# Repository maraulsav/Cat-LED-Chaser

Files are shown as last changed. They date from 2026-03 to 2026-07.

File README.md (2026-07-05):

# Cat-LED-Chaser
Hii! This is a cat shaped LED chaser. I wanted to make it as a keychain to be gifted to someone special for me during my highschool graduation later..
This is the final form of my cat LED casher



And here's the youtube video of my journey making this cat LED casher: https://www.youtube.com/watch?v=RgV0-7eemWM
See full built documentation at JOURNAL (1).md

## 3D View
Front



Back



## Features
- NE555P (555 Timer)
- CD4017 (Integrated Circuit)
- 10 LEDs
- 2 Capacitor
- 2 Resistor
- 1 Variable Resistor
- 1 Slide witch
- 1 Battery Socket
- 1 Battery

## PCB
My PCB is made in KiCad These are the footprints I used
- Battery: Battery_Panasonic_CR2032-HFN_Horizontal_CircularHoles
- Capacitor_THT:CP_Radial D5.0mm_P2.00mm
- LED_THT:LED_D3.0mm
- Resistor_THT:R_Axial_DIN0207_L6.3mm_D2.5mm_P7.62mm_Horizontal
- Variable Resistor: Potentiometer_THT: Potentiometer_Vishay_T93YA_Vertical
- SW SPST: Button_Switch_THT_SPST:SW_Push_1P2T_Vertical_E-Switch_800UDP8P1A1M6
- TestPoint: Connector PinSocket 2.54mm:PinSocket 1x01 P2.54mm Vertical
- NE555P: Package_DIP: DIP-8_W7.62mm
- 4017: footprints: N16

Here is my schematic:



and my PCB:



## BOM
You can see the BOM in Blinky Board-bom.csv files

## Additional Thingy
Thankyou for HackClub and  KiCad for making this project possible

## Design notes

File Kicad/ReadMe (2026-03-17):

Here's all the KiCad files. 
If you want to built your own LED chaser you can use my schematic design here!

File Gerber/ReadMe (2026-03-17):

Here's the gerber files of my LED casher cat shaped. 
You can download it and compres it all into one zip files. 
Then, you can upload it in the JLCPCB, it should be automatically generate the shape

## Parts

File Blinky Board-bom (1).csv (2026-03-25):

Name | Purpose | Quantity | Total Cost (USD) | Link | Distributor
Tokopedia Delivery | To deliver the components | 1 | 2.86 | https://www.tokopedia.com/cart/checkout?t_id=1774435593040&t_st=2&t_pp=cart&t_efo=cart&t_ef=&t_sm=&t_spt=cart | Tokopedia
E-Post Delivery | Delivery for the JLCPCB | 1 | 1.50 | https://cart.jlcpcb.com/quote?spm=jlcpcb.Public.2006 | JLCPCB
PCB Printing 5x | For holding all the components together | 1 | 4.00 | https://cart.jlcpcb.com/quote?spm=jlcpcb.Public.2006 | JLCPCB
Battery CR2032 | Power supply | 2 | 0.65 | https://www.tokopedia.com/panasonic-battery-indonesia/panasonic-baterai-kancing-lithium-coin-cr2016-cr2025-cr2032-cr2032-1pc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 | Tokopedia
Battery Socket CR2032 5x | For the battery placement | 1 | 0.27 | https://www.tokopedia.com/iwantelectronics/soket-baterai-3v-tempat-holder-case-baterai-kancing-3v-cr2032-battery-socket-cr2032-socket-battery-3v-cr2032-socket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 | Tokopedia
slide switch | To make sure the battery is not overused. regulating power | 1 | 0.10 | https://www.tokopedia.com/indo-ware/3-pin-saklar-geser-mini-toggle-switch-slide-1p2t-3pin-ss12d00-g3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 | Tokopedia

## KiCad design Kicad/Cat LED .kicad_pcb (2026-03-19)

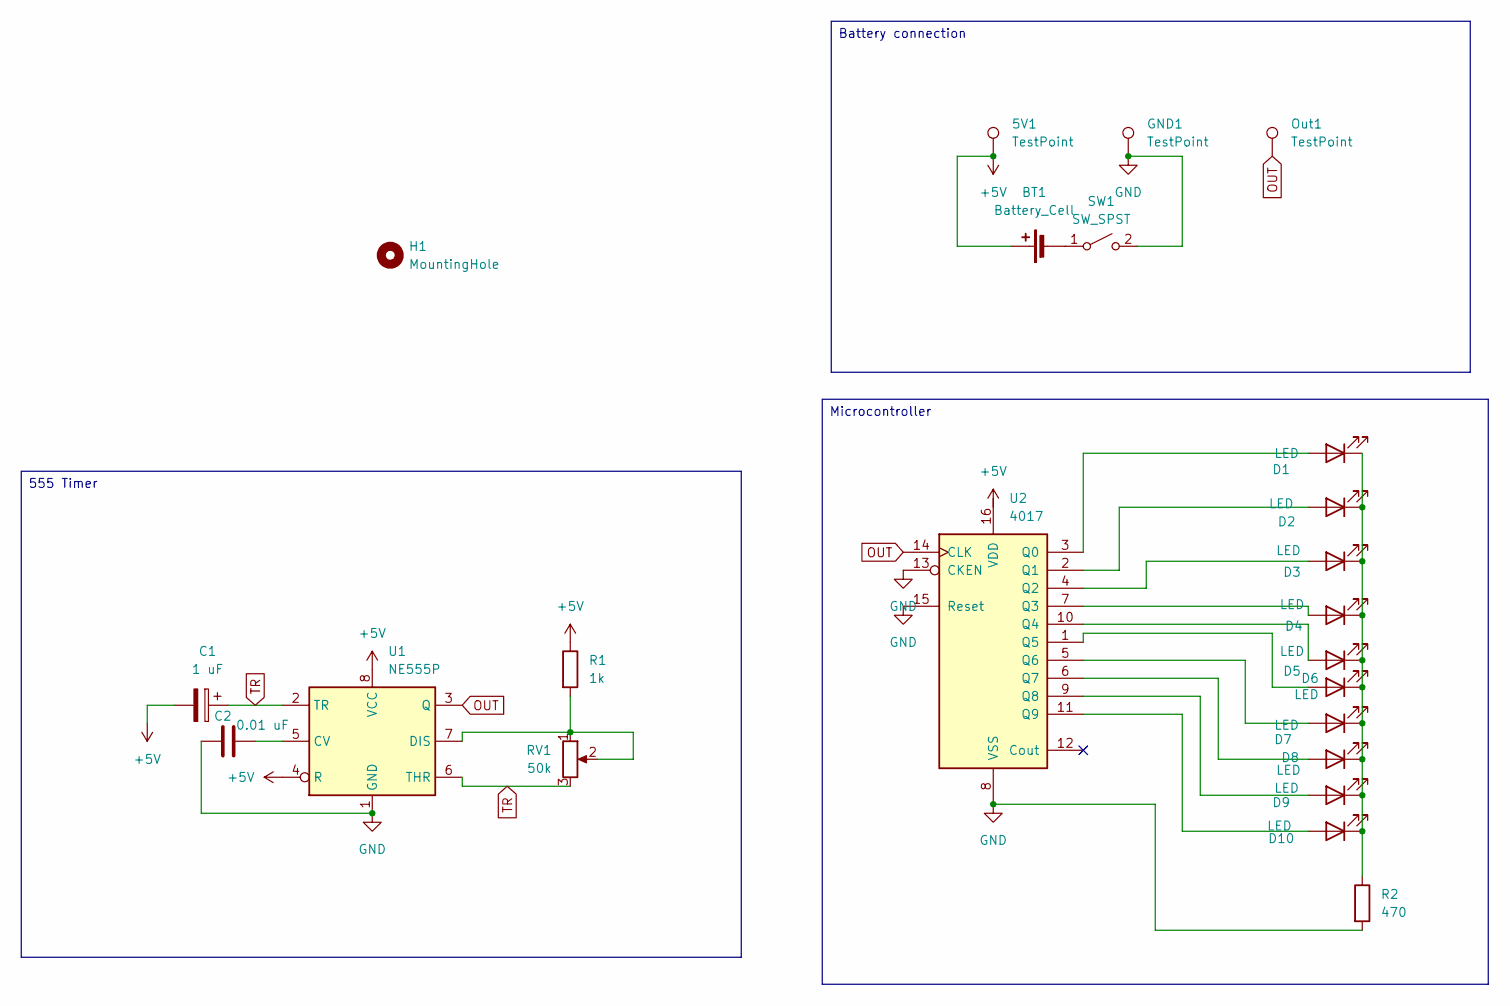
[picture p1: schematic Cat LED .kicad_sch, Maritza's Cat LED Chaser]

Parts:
5V1: TestPoint; PinSocket_1x01_P2.54mm_Vertical
BT1: Battery_Cell; Battery_Panasonic_CR2032-HFN_Horizontal_CircularHoles
C1: 1 uF; CP_Radial_D5.0mm_P2.00mm
C2: 0.01 uF; CP_Radial_D5.0mm_P2.00mm
D1, D2, D3, D4, D5, D6, D7, D8, D9, D10: LED; LED_D3.0mm
GND1: TestPoint; PinSocket_1x01_P2.54mm_Vertical
H1: MountingHole; MountingHole_4mm
Out1: TestPoint; PinSocket_1x01_P2.54mm_Vertical
R1: 1k; R_Axial_DIN0207_L6.3mm_D2.5mm_P7.62mm_Horizontal
R2: 470; R_Axial_DIN0207_L6.3mm_D2.5mm_P7.62mm_Horizontal
RV1: 50k; Potentiometer_Vishay_T93YA_Vertical
SW1: SW_SPST; SW_Push_1P2T_Vertical_E-Switch_800UDP8P1A1M6
U1: NE555P; DIP-8_W7.62mm
U2: 4017; N16

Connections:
+5V: 5V1.1, BT1.1 (+), C1.2, R1.1, U1.4 (R), U1.8 (VCC)
GND: C2.2, GND1.1, R2.2, SW1.2 (B), U1.1 (GND), U2.8 (VSS), U2.13 (CKEN), U2.15 (Reset)
unnamed: BT1.2 (-), SW1.1 (A)
unnamed: D1.2 (A), U2.3 (Q0)
unnamed: D1.1 (K), D2.1 (K), D3.1 (K), D4.1 (K), D5.1 (K), D6.1 (K), D7.1 (K), D8.1 (K), D9.1 (K), D10.1 (K), R2.1
unnamed: D2.2 (A), U2.2 (Q1)
unnamed: D3.2 (A), U2.4 (Q2)
unnamed: D4.2 (A), U2.7 (Q3)
unnamed: D5.2 (A), U2.10 (Q4)
unnamed: D6.2 (A), U2.1 (Q5)
unnamed: D7.2 (A), U2.5 (Q6)
unnamed: D8.2 (A), U2.6 (Q7)
unnamed: D9.2 (A), U2.9 (Q8)
unnamed: D10.2 (A), U2.11 (Q9)
unnamed: C2.1, U1.5 (CV)
unnamed: R1.2, RV1.1, RV1.2, U1.7 (DIS)
OUT: Out1.1, U1.3 (Q), U2.14 (CLK)
TR: C1.1, RV1.3, U1.2 (TR), U1.6 (THR)

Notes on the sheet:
Microcontroller
Battery connection
555 Timer

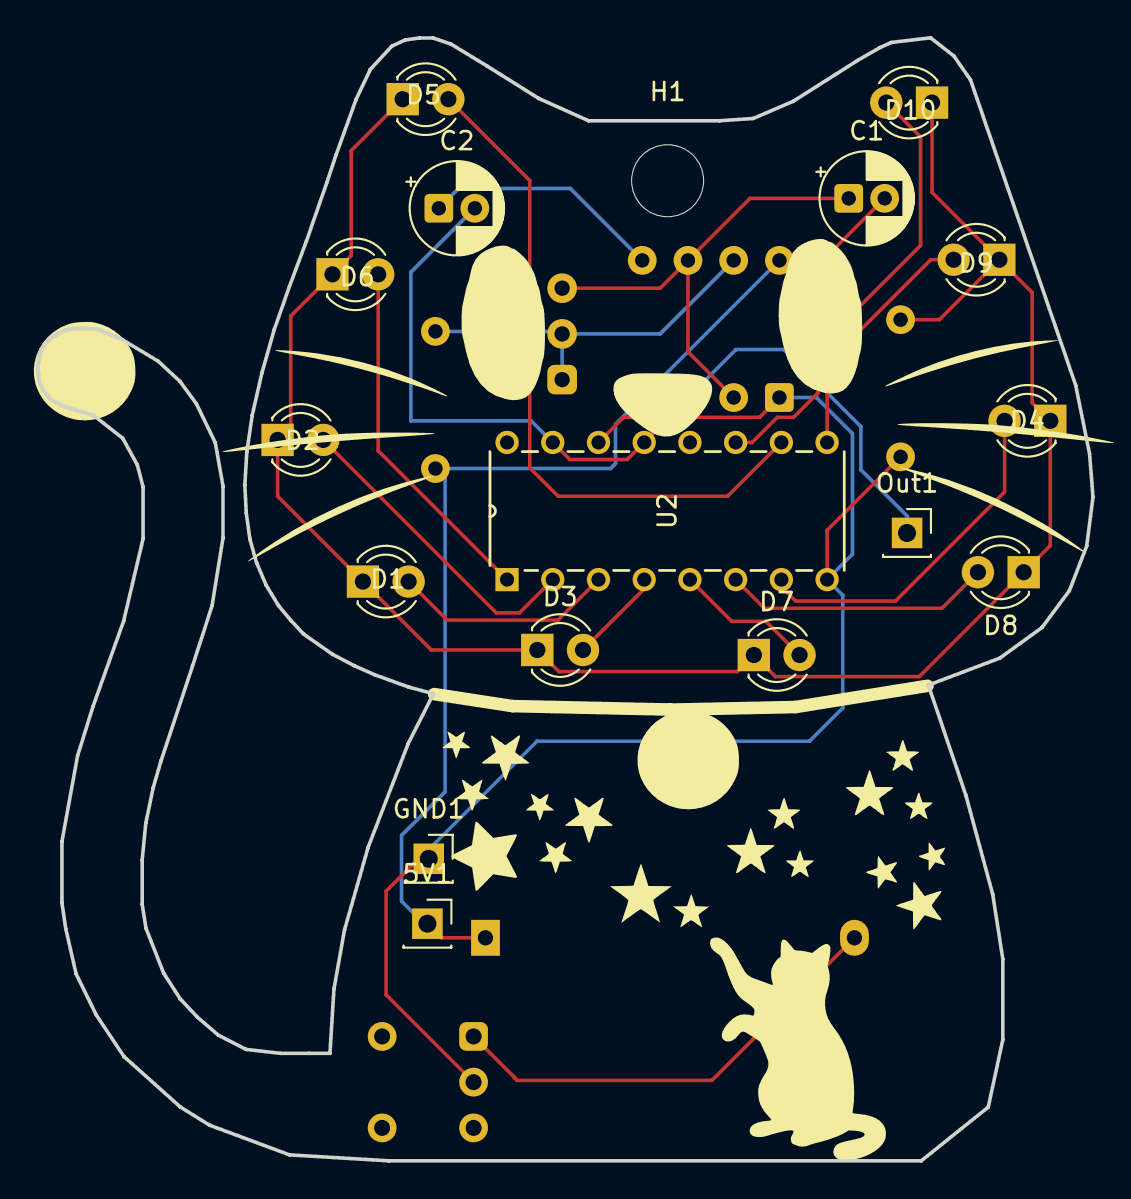
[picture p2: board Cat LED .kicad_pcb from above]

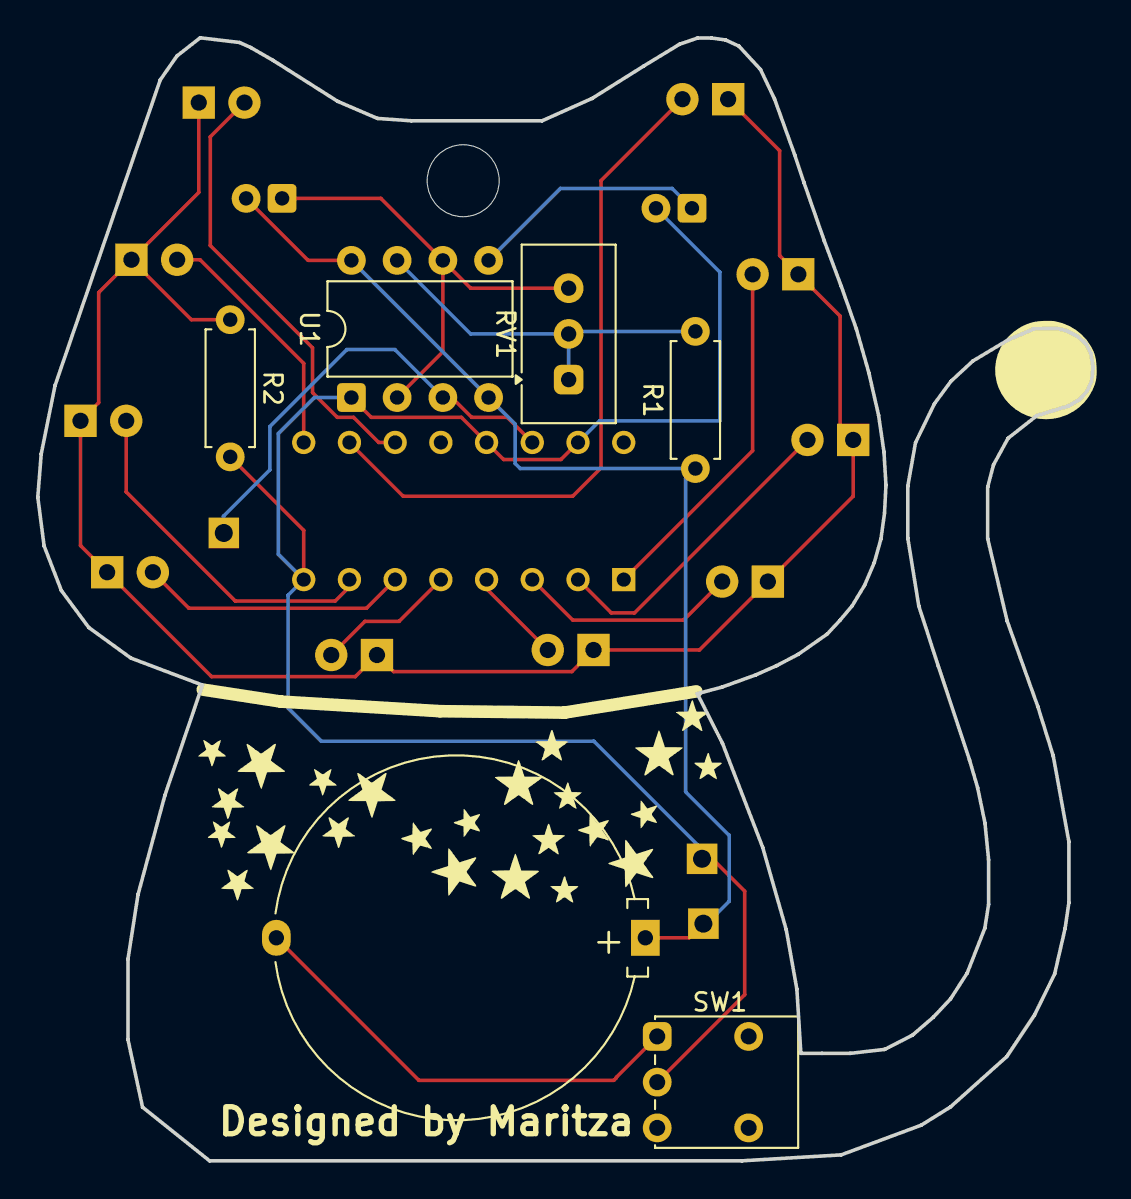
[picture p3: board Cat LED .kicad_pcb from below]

Board: 2 copper layers, 58.6 x 62.4 mm, 23 parts (6 on the bottom side), 18 nets.

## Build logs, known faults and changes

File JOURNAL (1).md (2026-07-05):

<!--
  This journal is auto generated by Stasis.
-->

# 5/4/2026 1 AM - Fix It!

_Time spent: 2h_

Hii guyss.
So after asking the expert I found thaat my connection is the one that wrong :v
Welp
yea so I didn't connect the 5V battery to the IC..  


I am missing this connection

So I took a jumper wire and solder it to the PCB
And It worked !



YEAYYY FINALLYYY




# 5/3/2026 12 PM - Debugging and Soldering (Again)

_Time spent: 3.5h_

Hi, so following my previous journal, now after I came to school and trying out with the 9V battery, I discover that it still yet only red one that lights up. Yeah it is not my eye that mistakenly see colors nor because its the only color that can light up in the PCB 

(As I thought that because I am using the 3V battery initially, the 3V battery cannot power up the blue LED; I see from google that the red LED require less voltage supply)

However, there is a thing that I noticed. When I touch the positive part of the LED beside the eye of the cat which the original that can turn on, like the below picture.


Then suddenly a different blue LED turn on while the red one turns off.


I get really curious after that.. like there must be something wrong with the battery right? like how can a current flow to my hand can turn on another side of LED. Like, I didnt even touch the other LED with my finger so I can say it is grounded (?) is it like that(?) 

So because yeah the LED that turn on only that two different color of LED.. then  I think that I cannot really jump into conclusion of whats wrong with my PCB now.. As different color require different voltage.. 

So I soldered another PCB this time all in yellow color.
I learnt from my previous mistakes: to stay focused.
I turn it on. Then...

only one LED that turn on, the LED beside the eye.. Still the same as before. Even when I test it by touching the positive part of the LED.. The  one that turn on is the LED below the chin



Well time to ask the expert
Keeping an update later! Byeee





# 4/29/2026 7 AM - First soldering

_Time spent: 4.5h_

Hi! In this session I solder the parts I have been received to my PCB.. I think overall its better than my first blinky board.. I think somehow the PCB that I got from JLCPCB can like..connected with the soldering iron (so it is not crumbled up like drop of water). 

However I must remind you guys to stay focused.. because yea, at first its all going okay up until I need to solder my LED.. Yea I think I kind of slack off and I accidentally put the LED at the behind on the cricuit board. 

This is my first time desoldering things, and it was.. horrible. Like the desoldering tool that I got still cannot catch all the soldering iron in the PCB so its still clogged up. I think I spent hours in this, trying to figure our how to desolder.

So, what I did to disattach the LED from PCB is that
1. Add more soldering iron to the pin.. I know this can be sound confusing but the explanation is that when you add more soldering iron when it is heat up the pin is loosened up better rather when it contain few soldering iron.. I think it is because soldering iron when heated became a liquid and it is esier to transfer heat when there is more soldering iron component on the pin.

2. Heat up the soldering iron and push the component. If you have a helping hand I suggest you to use it.. Avoid direct contact. As the pin really hot and also there is a chance where the solder accidentally get touched by your skin (This is what happen to me btw, so yea be careful)

Yea.. shortly that what I did to desolder my PCB. But yea keep in reminder I used a cheap desoldering iron that work (supposedly) by sucking up the soldering iron.. So if you have more reliable desoldering tools just use it.

This is what my PCB when in the middle of me trying to get the LED from the back of my PCB to the front



Oh yeah and try to be tidy when you proceed your project because this was my workplace



Well yea messy..

And I accidentaly put another LED(which I checked later it is a red LED) (whereas I want it to be all blue LED). 
I just realised this when I decide to call it a day.. and then I saw in there is still one blue LED left in the plastic whereas the LED had been all fulfilled..

Then when I tried to connect the battery to it.. Only one red LED beside the eye turned on with a dim light.. Yea disaster.. I will continue tomorrow




# 3/17/2026 8 AM - Schematic and PCB Design

_Time spent: 5h_

Hi all!
In this project I want to make a LED chaser with the shape of a cat.. It is for one of my teacher, as in may I will be like graduated from my school and I wanted to make something special to her..

For the schematics I followed the tutorial.  However because  I wanted to make this as a keychain, I also add a battery holder and a switch into the design.



After that, I designed the PCB with the shape of a Cat..
How do I built the cat design? 
So, first I search for a cat design in the internet, that I import the picture as a foot print using the image converter in KiCad. After that, I imported the foot print and use edge cut line to determine the outer line. Oh, and my recommendation is that you have to set the edge cut lines to 2 mm, because when I used the default the edge cut of 0.5 mm, it didn't work because of ambigous line intersection.. (but it can be perhaps because of my skills). 

After you trace all of that, place the component inside of the trace. I recommend you to place your microcontroller first, because the other components placement depend on it, as they need to take the shortest way possible.. This is just my recommendation so that the wiring part is clearer. After wiring, I decorated  the PCB using footprints pictures, like the stars, eyes, nose.



This is the result of my LED chaser
Cute cat, I think

pretty easy to made for ur loved one, I really recommend this project &gt;v&lt;
